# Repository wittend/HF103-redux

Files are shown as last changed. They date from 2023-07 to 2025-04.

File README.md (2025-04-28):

# NOTE: Just testing this REPO right now. - It may not work correctly!!
# HF103-redux
### A rework of an HF SDR using USB3 derived from a design developed by Oskar Stella, IK1XPV.
This variant is meant as a straw-man starting point for discussion of project options by members of the HamSCI and TAPR groups for scientific data-collection applications.  

It is a re-capture of design elements drawn from  Oskar's HF103, BBRF103, and other sources into a schematic drawn in KiCad.

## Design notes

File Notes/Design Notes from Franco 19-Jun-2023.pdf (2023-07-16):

# Design Notes from Franco 19-Jun-2023

Franco VENTURI\ Mon, 19 Jun, 21:51 (10 hours ago)
to me, tangerinesdr, Majid, Rob, Tom, John

## A few quick comments

### Maximum Throughput:

regarding the maximum throughput achievable with the FX3 the best place to start IMHO is Cypress AN86947 (https://www.infineon.com/dgdl/Infineon-AN86947_Optimizing_USB_3.0_Throughput_with_EZ-USB_FX3-ApplicationNotes-v05_00-EN.pdf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) - as you can see there the maximum (https://www.infineon.com/dgdl/Infineon-AN86947_Optimizing_USB_3.0_Throughput_with_EZ-USB_FX3-ApplicationNotes-v05_00-EN.pdf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) throughput is achieved using an AUTO DMA channel with the GPIF II interface, 32bit wide, and with a clock rate of 100MHz (and with 4 DMA buffer of 8kB each - bulk transfer mode)

### Important App Notes:

if I remember correctly, Oscar Steila IK1XPV design is based on the 'cyfxbulklpauto' example (you can find it in 'cyfx3sdk/firmware/dma_examples/cyfxbulklpauto' in the FX3 firmware SDK file 'fx3_firmware_linux.tar.gz'), and on a couple of very useful application notes from Cypress/Infineon: AN65974 "Designing with the EZ-USB FX3 slave FIFO interface" (https://www.infineon.com/dgdl/Infineon-AN65974_Designing_with_the_EZ-USB_FX3_Slave_FIFO_Interface-ApplicationNotes-v17_00-EN.pdf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), (https://www.infineon.com/dgdl/Infineon-AN65974_Designing_with_the_EZ-USB_FX3_Slave_FIFO_Interface-ApplicationNotes-v17_00-EN.pdf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)
and the 'ping-pong' DMA buffers approach shown in AN75779 "How to implement an image sensor interface using EZ-USB FX3 in a USB Video Class (UVC) framework" (https://www.infineon.com/dgdl/Infineon-AN75779How_to_Implement_an_Image_Sensor_Interface_with_EZ-USB_FX3_in_a_USB_Video_Class(UVC)_Framework-ApplicationNotes-v13_00-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 fileId=8ac78c8c7cdc391c017d073ad2b85f0d)) (https://www.infineon.com/dgdl/Infineon-AN75779_How_to_Implement_an_Image_Sensor_Interface_with_EZ-USB_FX3_in_a_USB_Video_Class_(UVC)_Framework-ApplicationNote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)

### Previous Code:

when I looked at what he did a few years ago I didn't think it was exceedingly difficult; I remember the one thing to get right is the design of the GPIF II state machine using the program 'GPIF II Designer' (that I think runs only on Windows), but we can definitely look at what Oscar did and follow his footsteps (I think the design of his GPIF II state machine is in his GitHub repository too, so we can use that as a starting point)

### Keep Things Simple:

if I have to give you one advice is to try to 'keep things as simple as possible'; this is what Oscar did in his design of the BBRF103, which he was able to design and make in a relatively short period of time. I think the important thing is to get a prototype out that works even if it is not perfect and meet all the specifications. We can always improve from that but at least the first step is done.

### Choice of ADC:

regarding the choice of the ADC I don't think 14bit or 16bit makes much of a difference in terms of ENOB, since I read somewhere about diminishing returns at those resolutions (can't find the link now); since the FX3 GPIF II works with 16/32 bits at a time, using a 14bit ADC would give us two extra bits for each sample: one could be used for the overflow bit, and the MSB for the PPS from the GPSDO, which I think is what Tom is doing in the TangerineSDR.

### General advice:

and finally I expect that someone will eventually come out with the "ClementineSDR+" that uses the LTC2208-16, since for some reason they are dirt cheap on AliExpress.

73,

Franco K4VZ

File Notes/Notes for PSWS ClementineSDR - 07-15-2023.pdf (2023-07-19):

# Notes for PSWS ClementineSDR - 07-15-2023

## Includes progress with HF103-redux

Dave Witten, KD0EAG

## Recent activity

Continued work on redraw/capture of the design elements of Oskar Stella's HF103 and BBRF103 radio designs in KiCad. The HF103 is an HF only version. The BBRF103 design supports VHF/UHF and is a more direct predecessor of the RF-666, RF-888, and RF-888 MK-II designs. All may be descendants of a project called booyaSDR. All use the Cypress CYFX3SDK or its component chips. Several different LTC ADC chips are used, All very similar.
Introduced myself to Oskar Stella by email. Received his kind permission to ask questions (sparingly) about his designs.
Created an initial private GitHub repo for the resulting KiCad project. Invited some initial interested parties as collaborators. It is early-daze for this, lots to learn about how to make a KiCad project hang together in GitHub.
Though this schematic and all related documents will be open to all, I'm holding them 'private' until I'm sure that the repo works as intended.
Received a booyaSDR kit for study. So have Dave Larsen and Mike Hauan. Seller indicates that he has run out of stock due to Cypress CYFX3SDK's being unavailable. This is true for US distributors, but the SDK's are available (often at a premium) from overseas suppliers.
The individual SDK components seem to be in good supply.
Received an LTC2208-16 board to supplement the LTC2208-14 board that I have. Unfortunately, the one that I have is a variant that supports input data at >140 MHz. I should have bought the version that supports 1 MHz > 70 MHz. Not sure that I want to buy another board for ~$ 250.00.

## Plans for the next week:

Work on requirements document (!!)
Try to get to work with the Cypress SDK examples (!)
Make sure everyone who needs access to the GitHub has it.
Make especially sure that people who are interested are communicating about clocking issues are keeping everyone informed of their strategies.
Try to solicit feedback concerning schematic design.

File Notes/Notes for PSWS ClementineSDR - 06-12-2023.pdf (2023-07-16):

# Notes for PSWS ClementineSDR - 06-12-2023

Paths to pursue:

1. Platform revision
Platform Requirements
As much of functionality described in "TangerineSDR - Architecture and System Requirements" (Tom McDermott rev. 0.3, 30 May 2019) as possible.
2. Radio subsystem only
Implement as much of the functionality described in "TangerineSDR RF Receiver Module (RXM-5001D)" (Document Number: TSDR-RXM-5001D-REQ, Tom McDermott rev. 0.4, November 22, 2019) as possible.
Use existing RX-888 devices for RF Data Collection.
How to integrate?
Create adapter based on the Cypress FX3 SuperSpeed USB 3.0 peripheral controller to interface the existing TangerineSDR receiver module.
How much bandwidth support?
Coherent receiver support?
Design customized receiver based on the RX-888/BBRF103 design. Which A/D chip?
ADC9648 [dual-channel 14-Bit, 125 MSPS/105 MSPS, 1.8 V Dual] LTC2208-14/16 [14-Bit, 130Msps ADC].
???
Use For front end?
LTC6420-20 [dual-channel differential ADC driver with a fixed gain of 20 dB gain].
2. One Receiver or Two?
3. Features added:
Front end conditioning,
GPSDO discipline,
Time-stamping, etc.
4. Features removed:
RT820T2 VHF tuning?
3. Software integration
Verify that software drivers for intended platforms support existing use cases.
Understand organization and configuration of KA9Q-radio components relevant to project. Integration of data capture and collection into the HamSCI/PSWS storage architecture.
4. Immediate Actions:

Make certain that all existing HamSCi PSWS documentation is archived and accessible for future reference.
Investigate configuration of KA9Q-radio and understand its configuration.
Collect/Write documentation of KA9Q-radio and define its use as relates to this project. Acquire and test RX-888 devices to characterize their strengths/weaknesses to meet current needs.
Document fittness to purpose of existing RX-888 devices.
Acquire development tools required for customized design based on RX-888/BBRF103 designs.
Create sharable working schematic using KiCad.
Create sharable schematic and board designs for interface to existing TangerineSDR RF Receiver Module (RXM-5001D).
Create Github Repo for all documents and designs.
5. Development Tools:
CYUSB3Kit-003 (USB3 Interface dev. board) [Newark.uk, AliExpress]. CYUSB3Kit-007 (CPLD accessory board) [Newark.uk, AliExpress]. EZ-USB FX3 Software Development Kit [Infineon].
SuperSpeed Device Design by Example (book) [Amazon https://www.amazon.com/dp/1500588059?psc=1].
USB Complete v5 (book) [Amazon https://www.amazon.com/USB-Complete-Developers-Guide-Guides/dp/1931448280/134-6836790-4507607?psc=1].
AD/LTC Development board for ADC to be used. [Mouser, best bet].
KiCad footprints, symbols, 3D models for chips to be used [Ultra Librarian, various sources].

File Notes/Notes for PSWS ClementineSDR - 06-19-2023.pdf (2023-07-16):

# Notes for PSWS ClementineSDR - 06-19-2023

My (Dave, KD0EAG) activities during past week:

1. Track/receive Developer kits for CYUSB3kit
In hand (for sure) 1 CYSUB3Kit-003 board.
Hope to have two more CYSUB3Kit-003 boards by tonight (1 for Majid).
In hand (for sure) CYUSB3kit-007 CPLD add on board.
Hope to receive at least 1 more CYUSB3kit-007 CPLD add on board by end of month.
2. Productive call with Franco .
Discussed project goals and background.
Discussed path to hardware design.
Agreed that KiCad (free, open source) reference schematic is a good initial goal. Plan to have additional meets with interested participants as needed.
Agreed that design might hold some components external to facilitate future flexibility of design.
Front-end conditioning (filtering).
some aspects of time discipline.
some aspects of time stamping.
3. Attempted to keep interested parties informed of activities and interesting found documents. (Let me know if I am not including you properly).
4. Reading "SuperSpeed Device Design by Example" by John Hyde [Amazon https://www.amazon.com/dp/1500588059?psc=1].
Getting started with examples in this book.
5. Working on "Requirements" spreadsheet derived from:
"TangerineSDR RF Receiver Module (RXM-5001D) Requirements Document"
Document Number: TSDR-RXM-5001D-REQ, version 0.4 Date: Nov. 22, 2019
provided by Tom McDermott

My action Items:

1. Attempt to build a demo project for the FX3. Maybe more than one. Start with CPLD FX3-Slave FIFO CPLD Demo.
Will CPLD functionality be needed in final design (for timing stuff?)
Will I2C be needed for control functions?
2. Read BBRF103 and RX-888 code closely to better understand which sort of applications are possible and best suited to SDR designs.

from reading, it appears that an asynchronous FX3 Slave FIFO design may be the fastest and most appropriate architecture.
This may be a difficult strategy to design well. Don't know.
Need to find out what has been done in the past.
3. Choose ADC chips for reference schematic(s).
Probably choose LTC2208CUP-14 for first efforts because it is small and I have the DEMO854D-D board in hand.
Also have the AD9648-125EBZ board in hand, but it is bigger and looks complicated.
4. Need to discuss these things with Interested parties, esp. Tom McDermott, John Ackerman (maybe Franco, Rob, Phil when they return).
5. Get dev. tools packaged and sent to Majid ASAP (hopefully today if they arrive).
6. What else??

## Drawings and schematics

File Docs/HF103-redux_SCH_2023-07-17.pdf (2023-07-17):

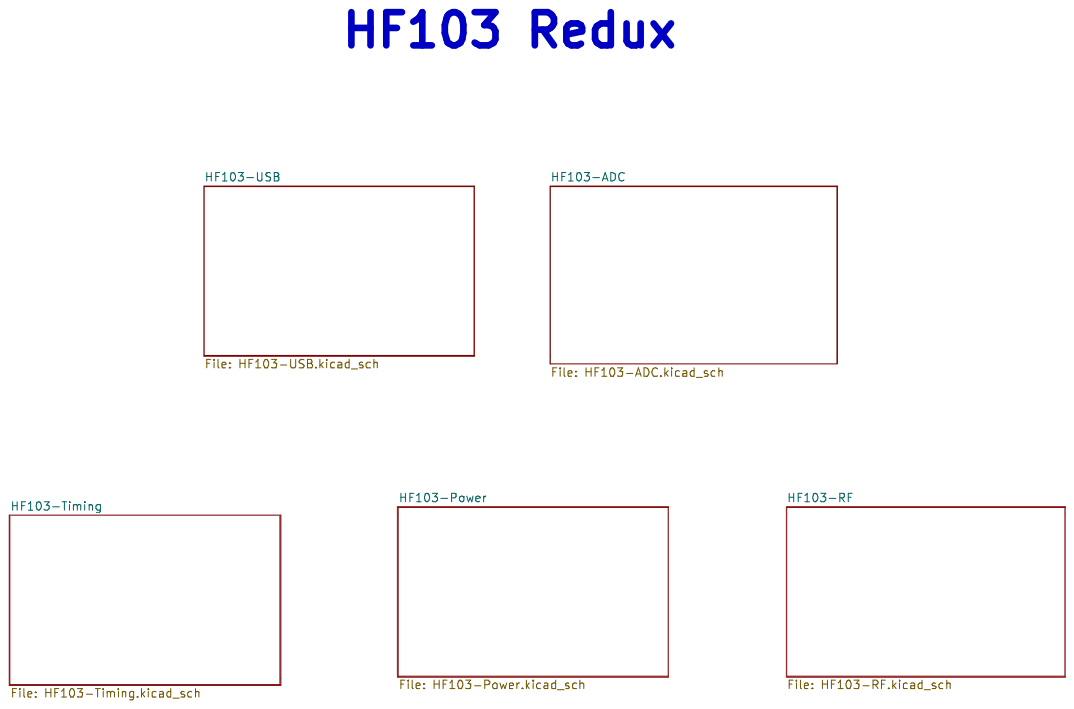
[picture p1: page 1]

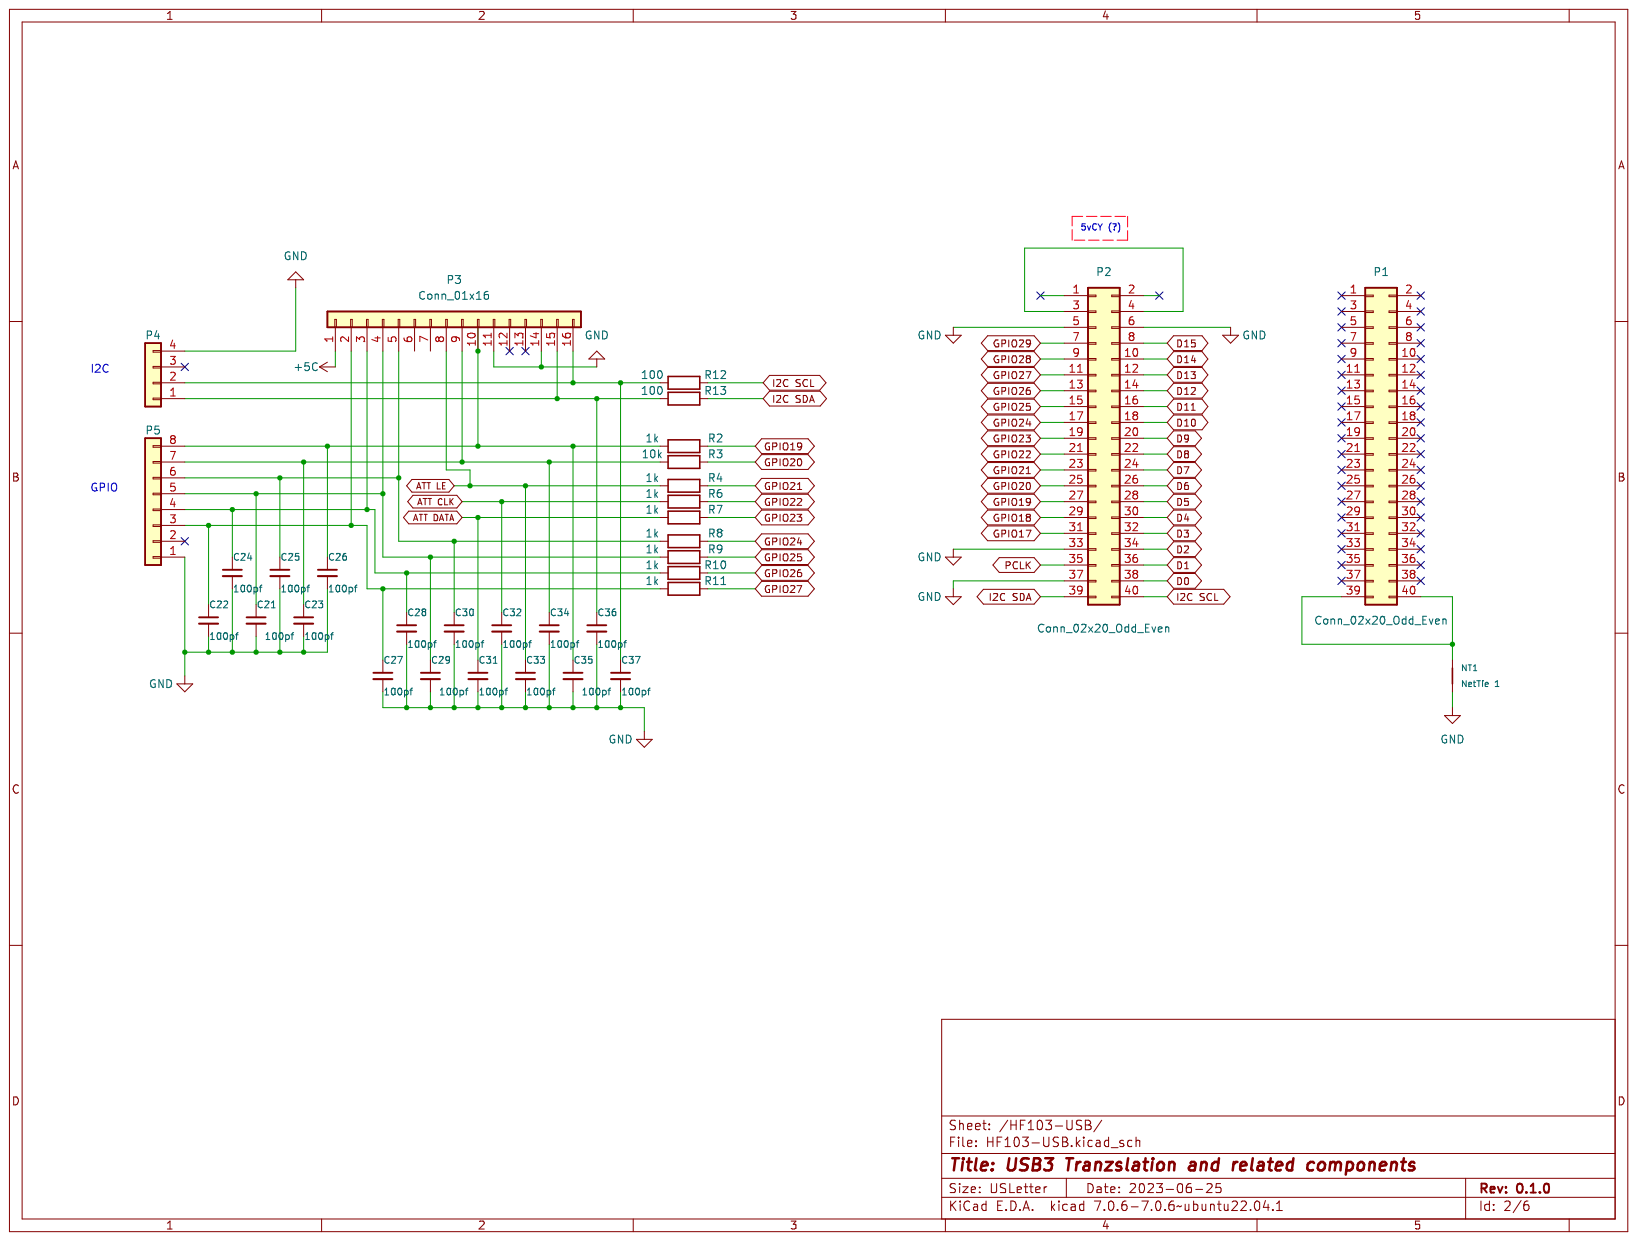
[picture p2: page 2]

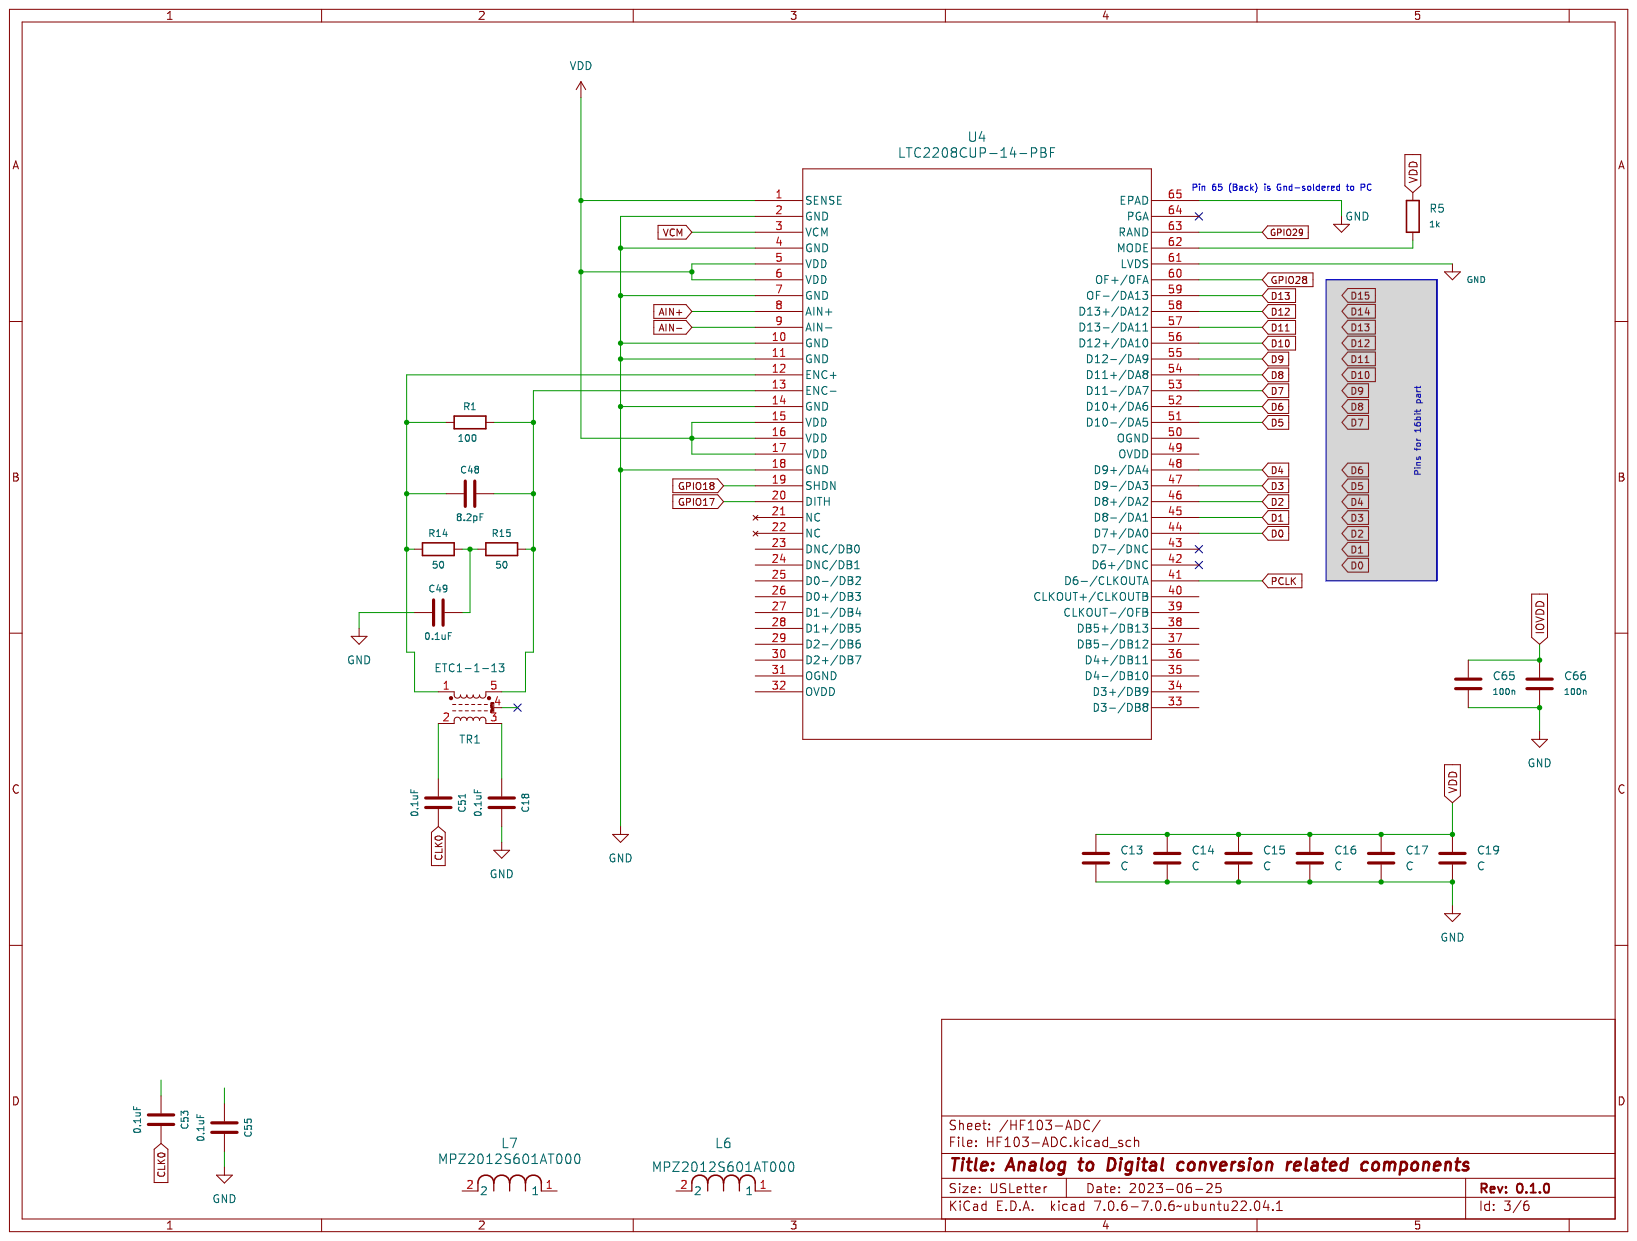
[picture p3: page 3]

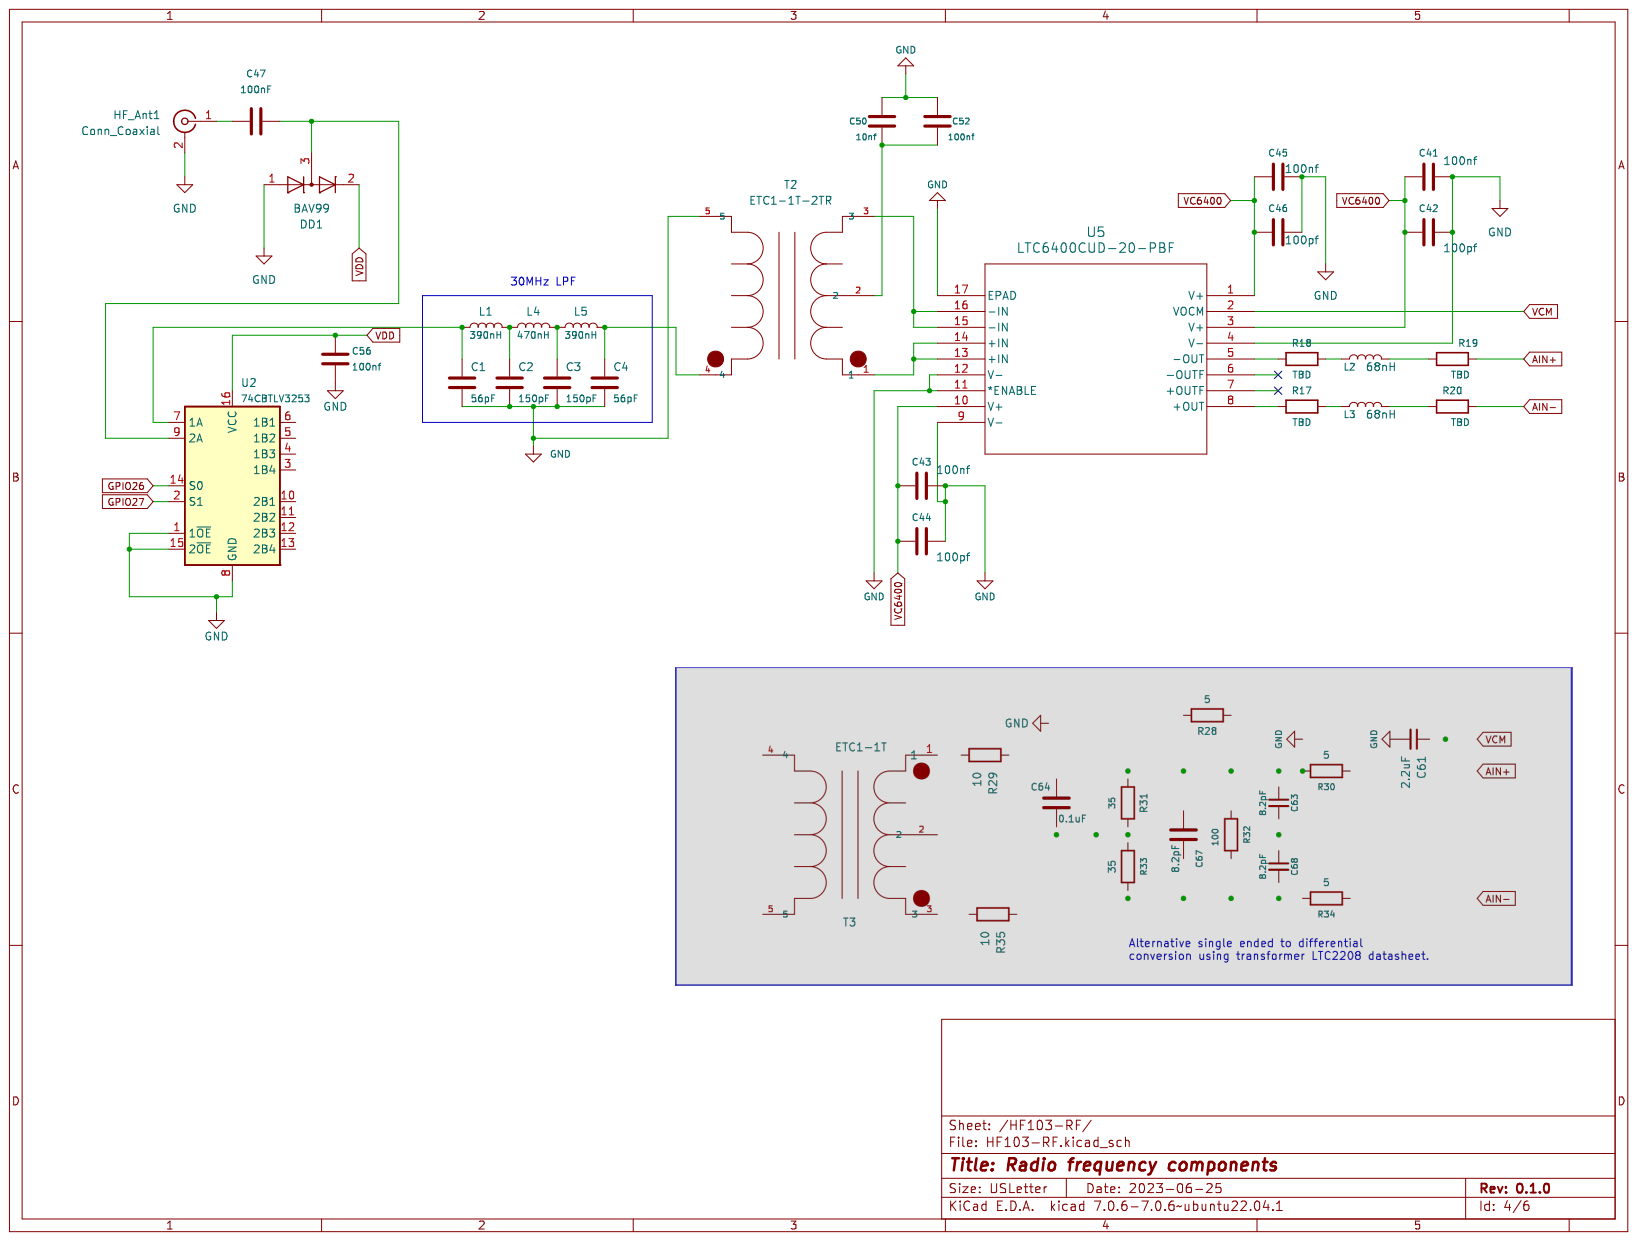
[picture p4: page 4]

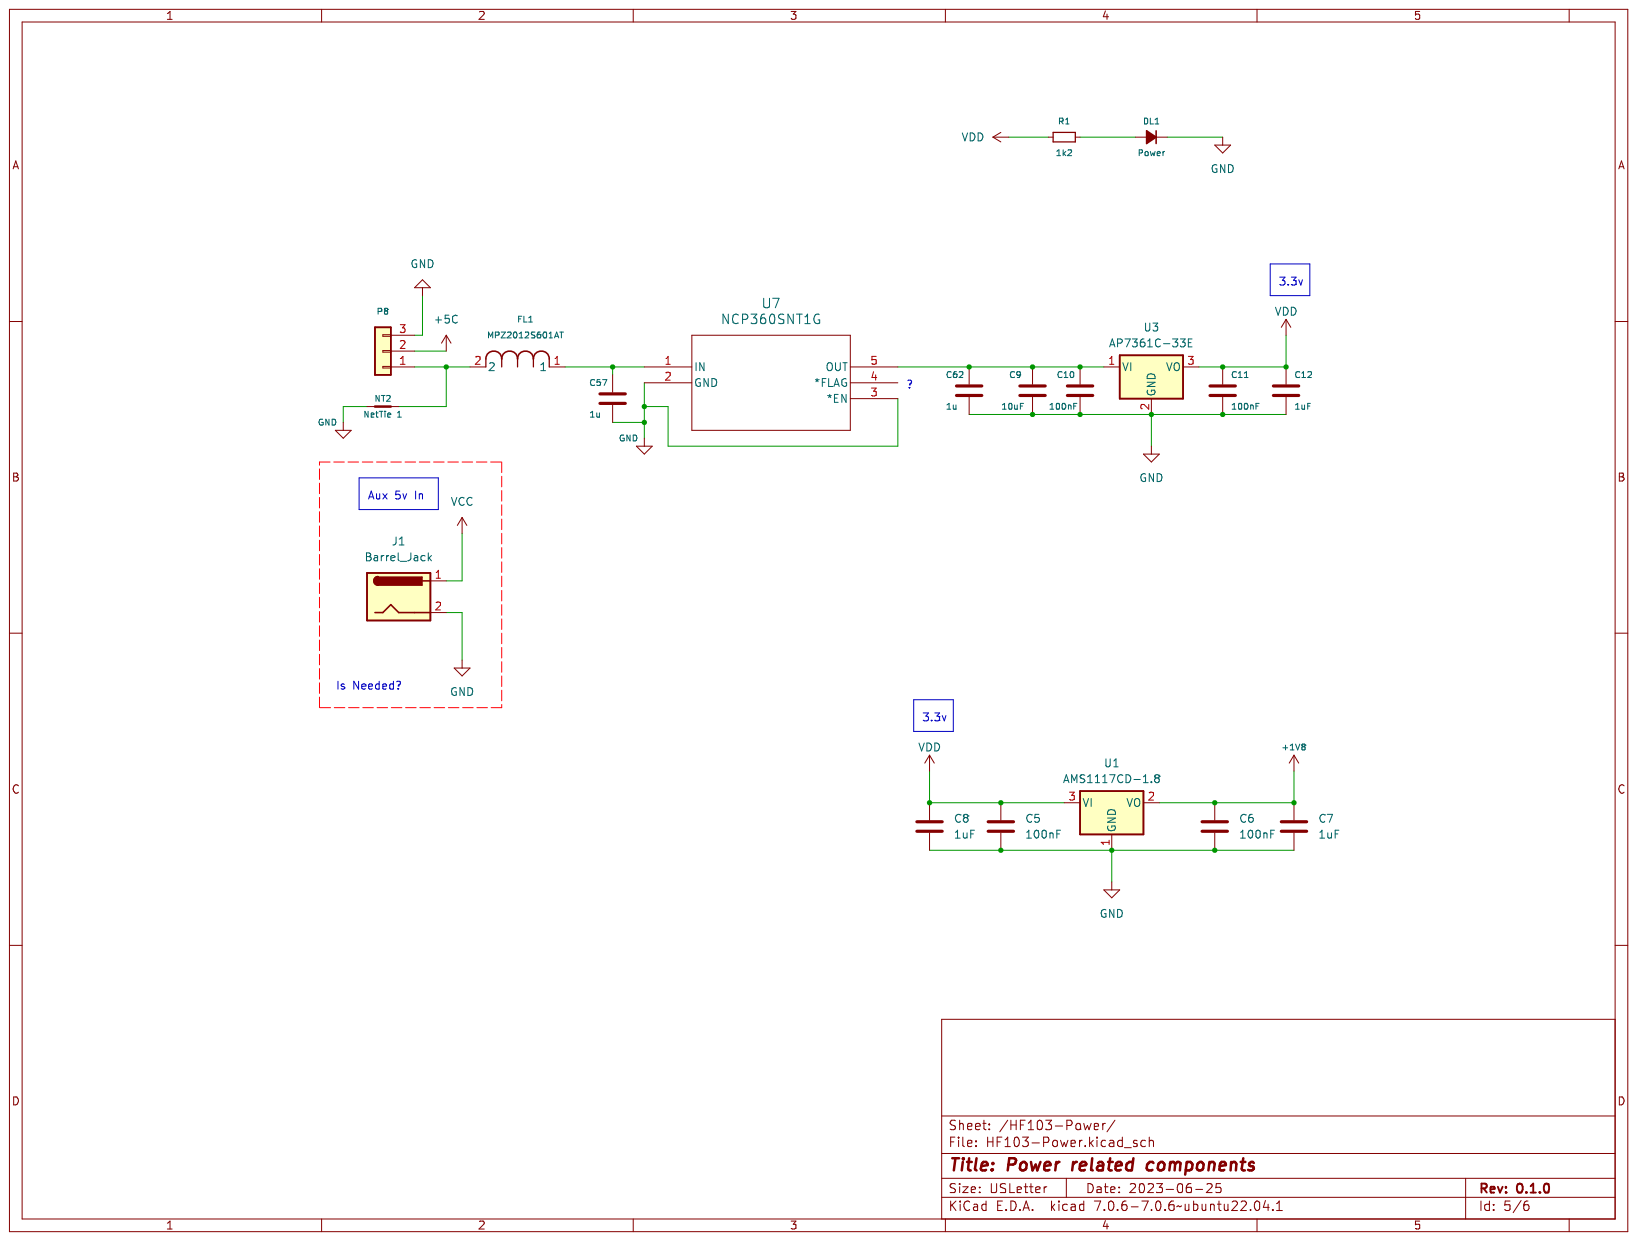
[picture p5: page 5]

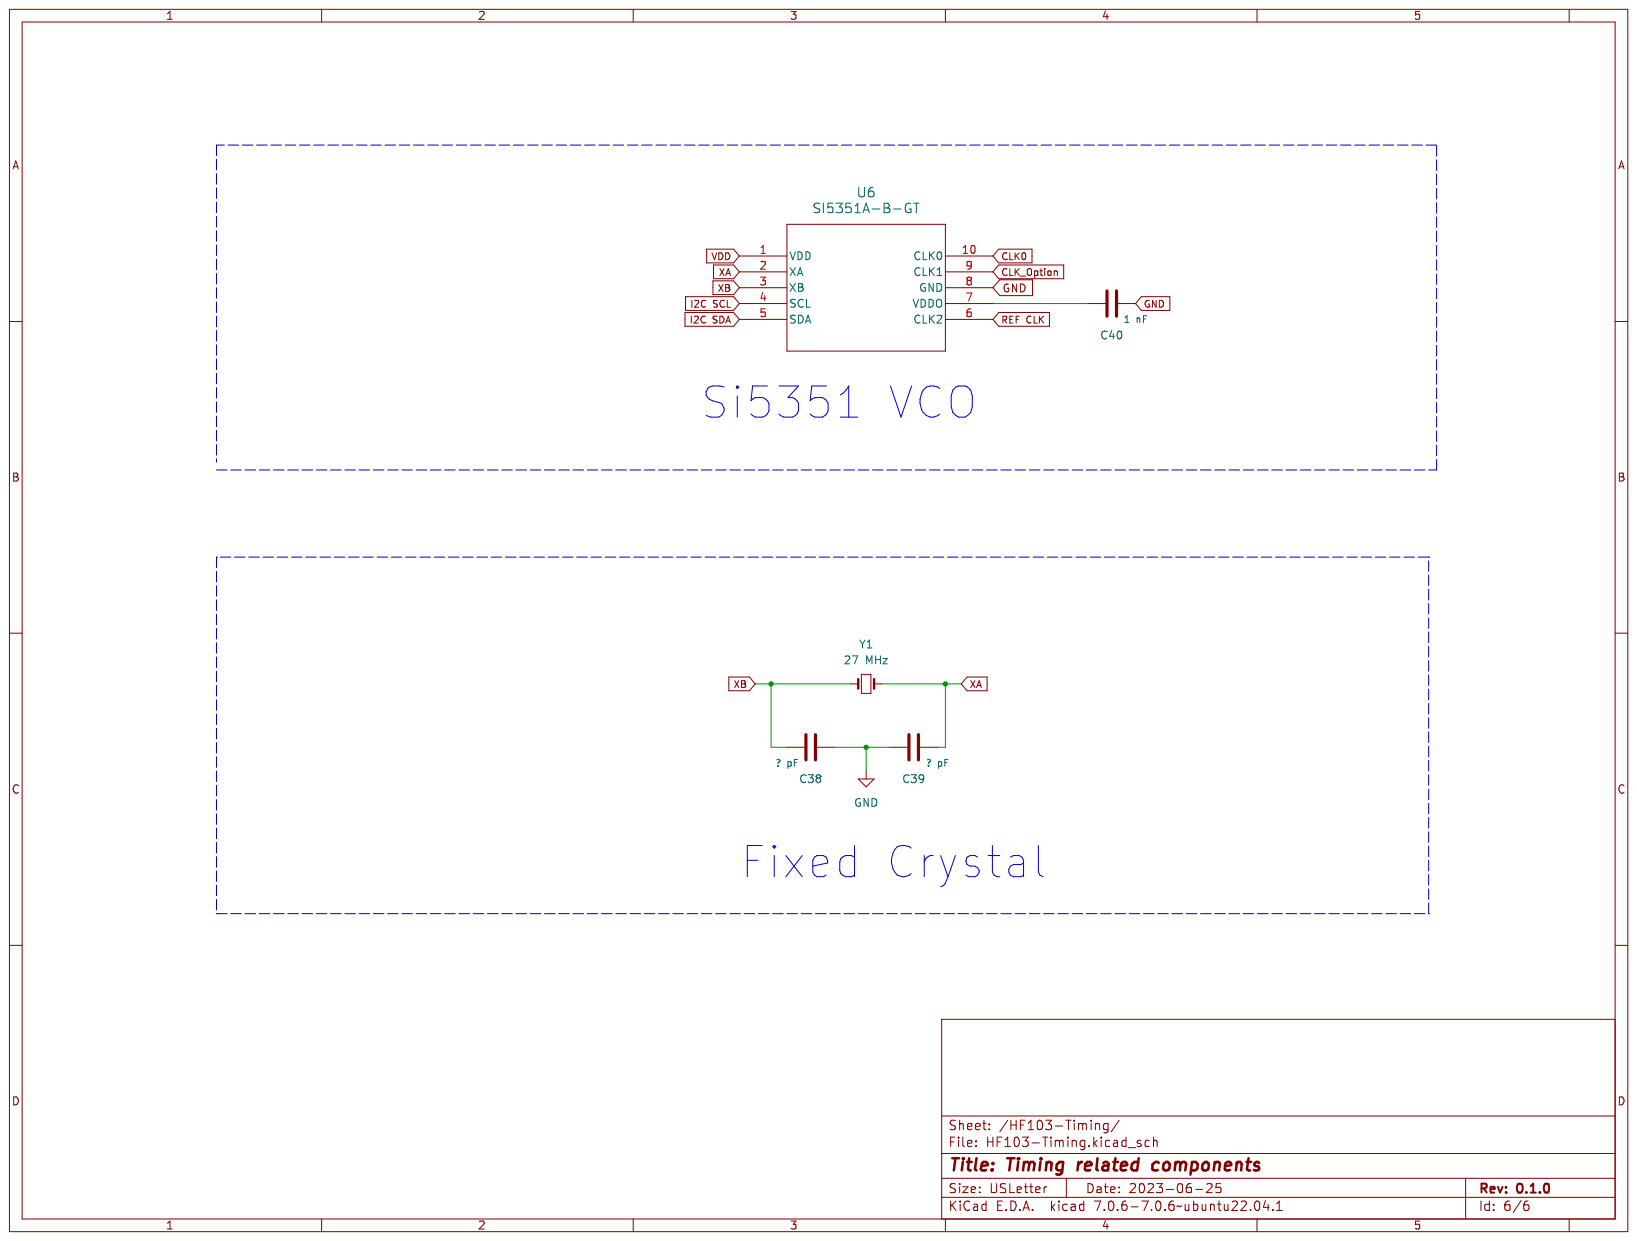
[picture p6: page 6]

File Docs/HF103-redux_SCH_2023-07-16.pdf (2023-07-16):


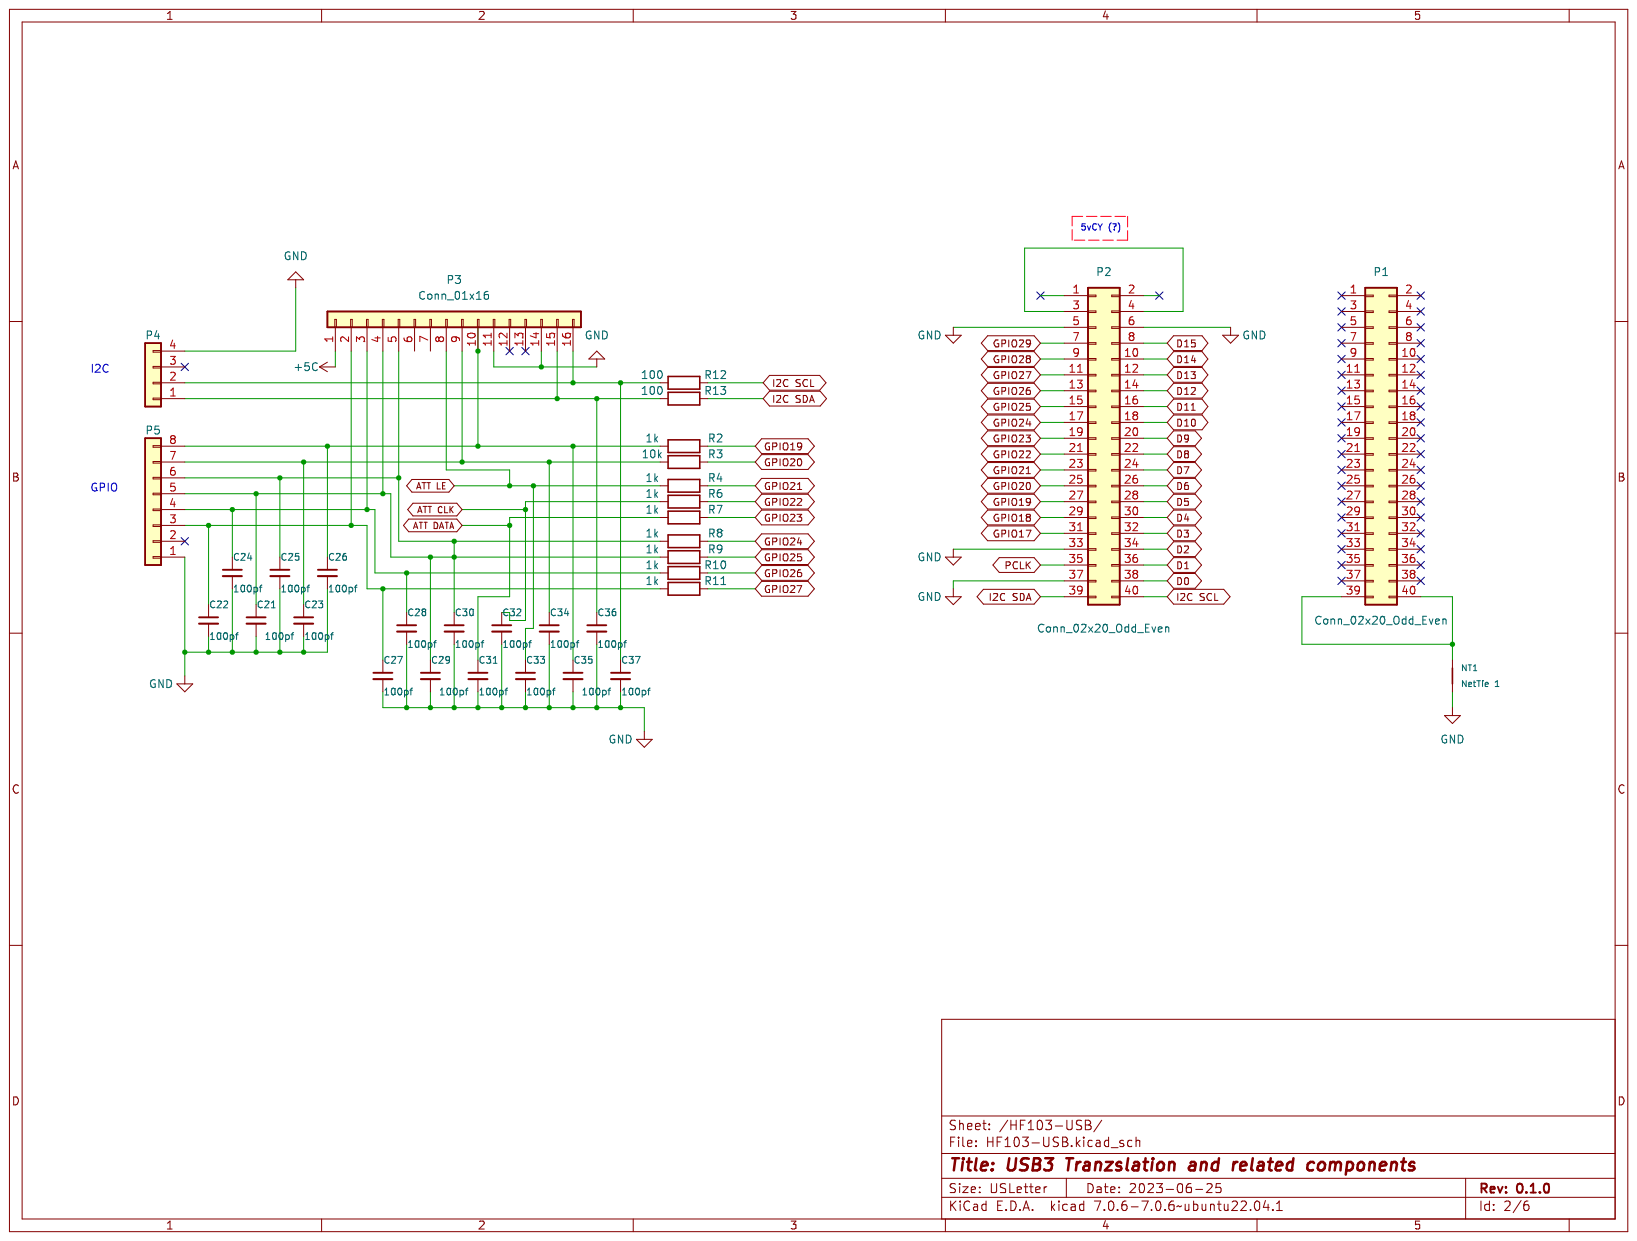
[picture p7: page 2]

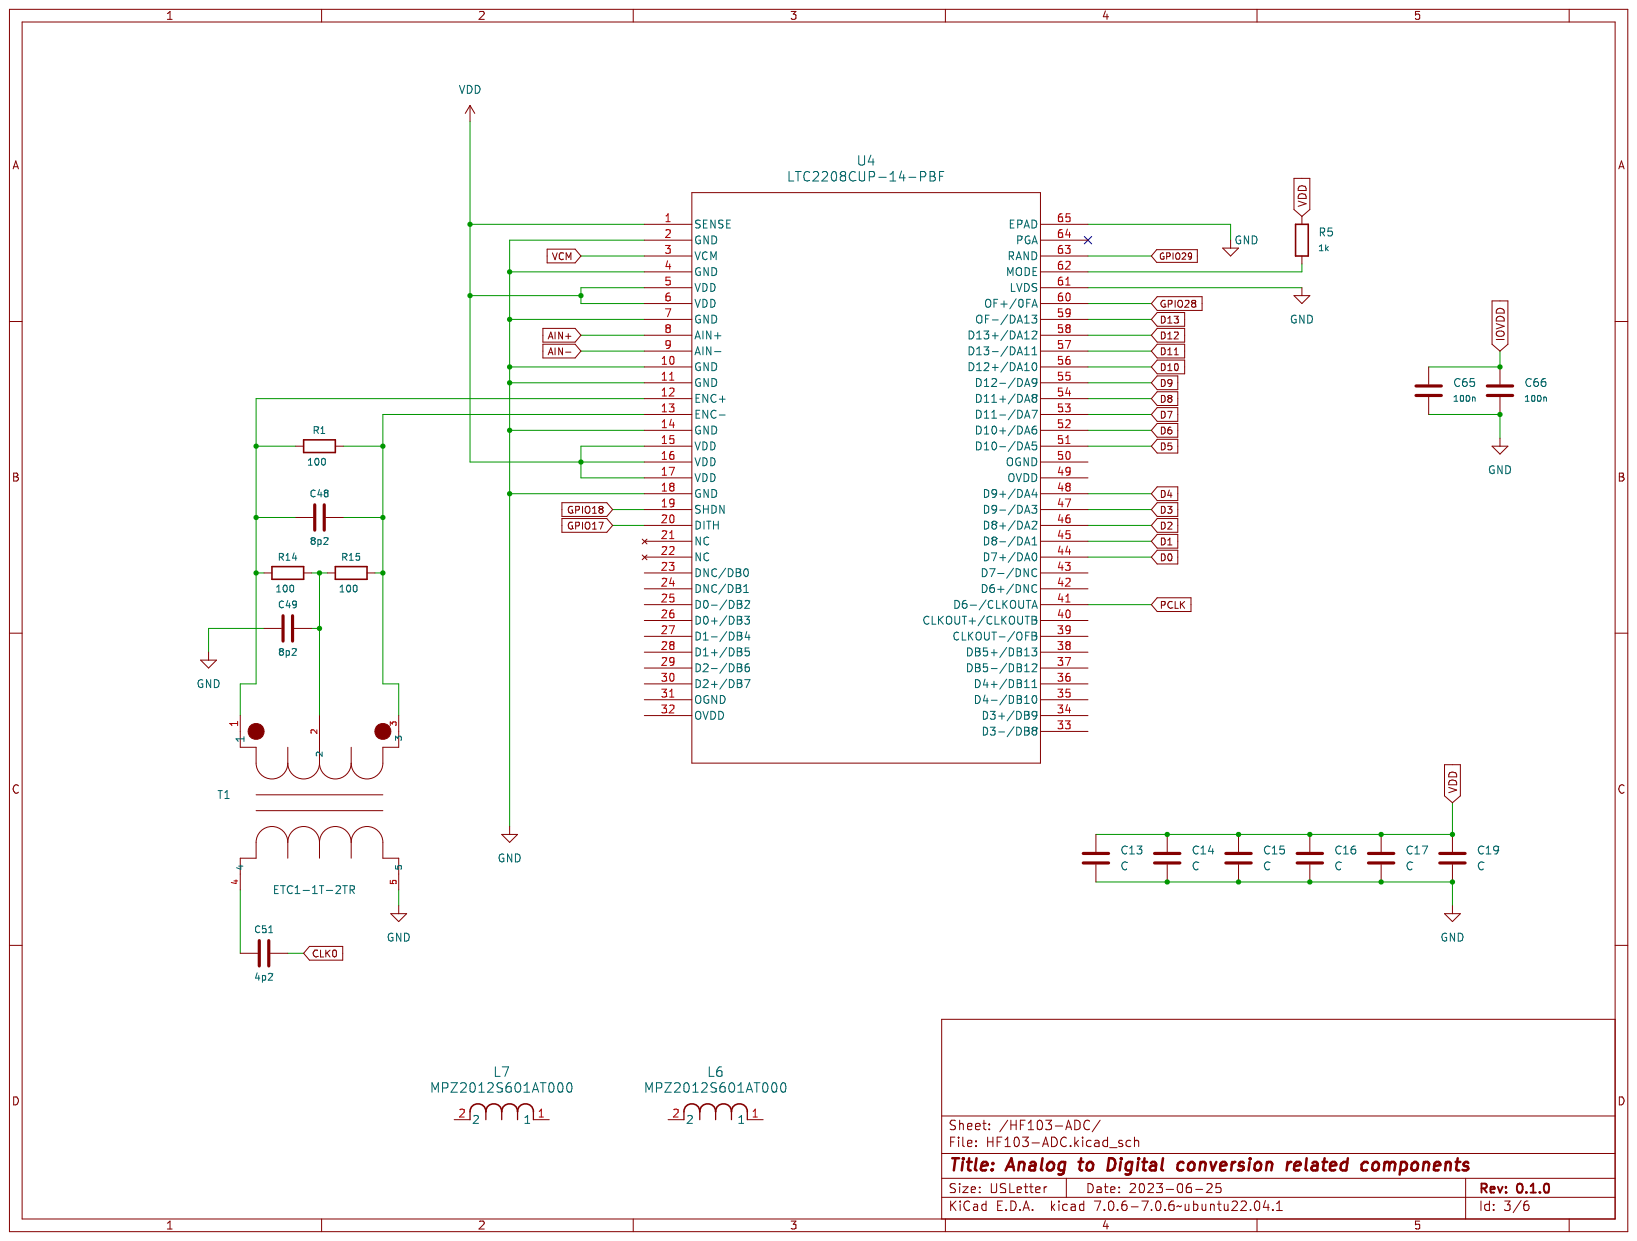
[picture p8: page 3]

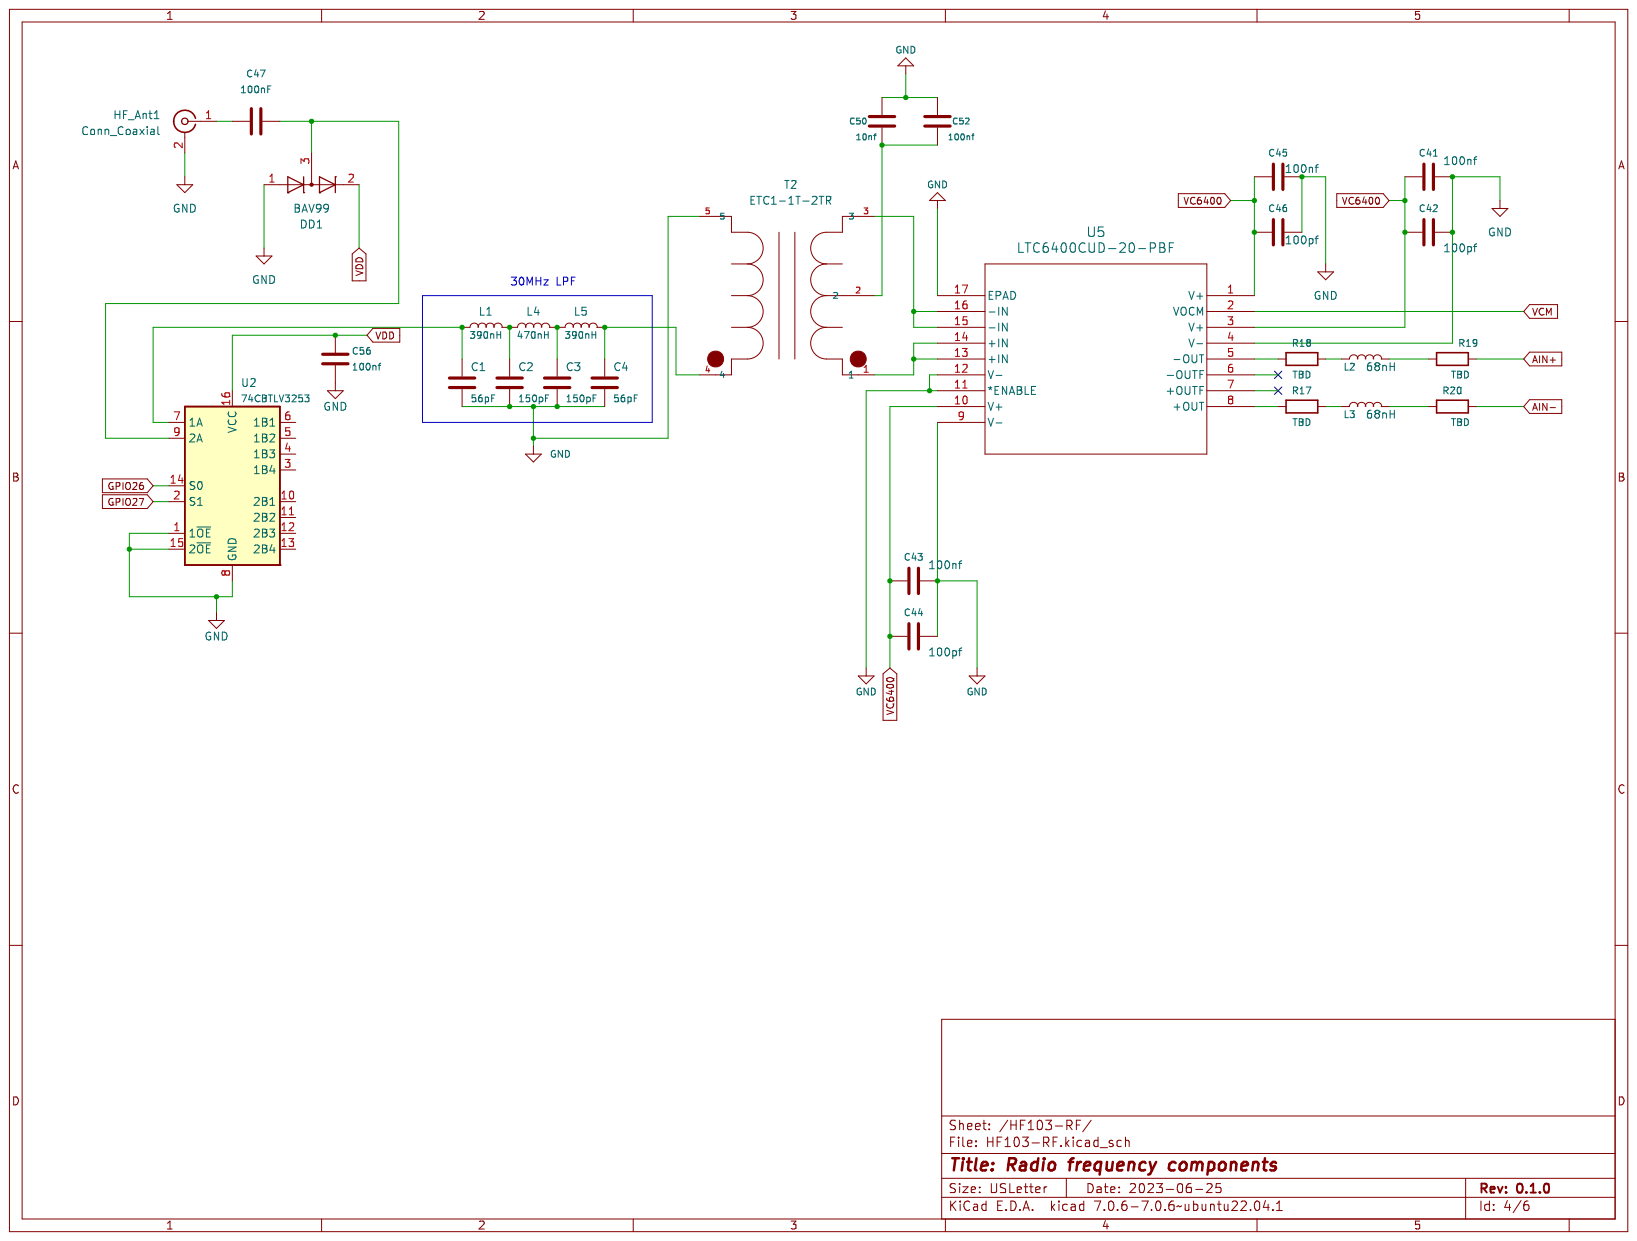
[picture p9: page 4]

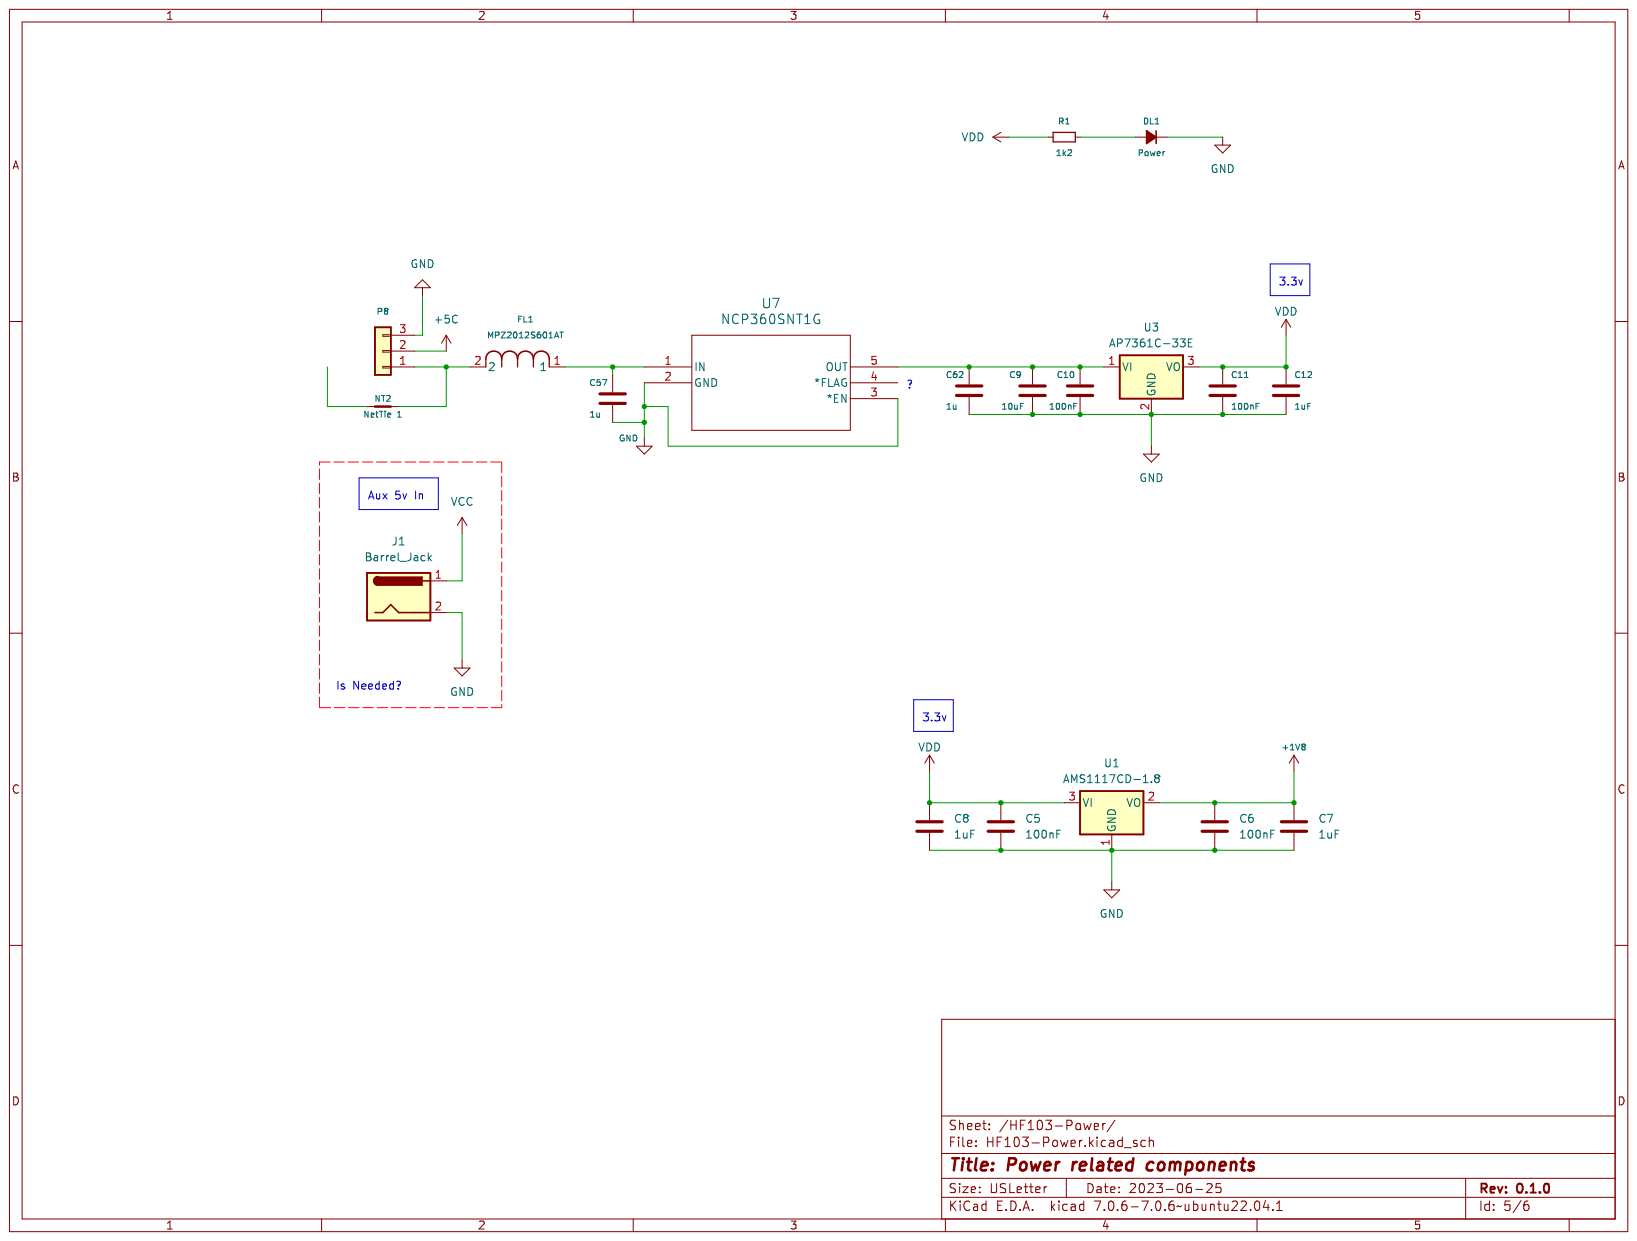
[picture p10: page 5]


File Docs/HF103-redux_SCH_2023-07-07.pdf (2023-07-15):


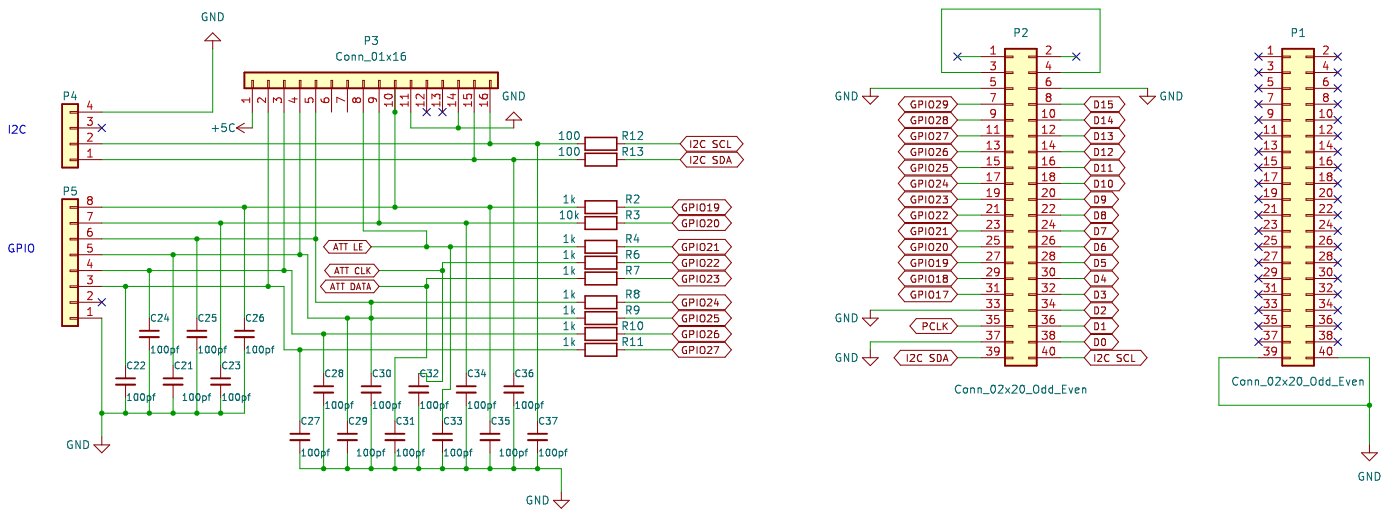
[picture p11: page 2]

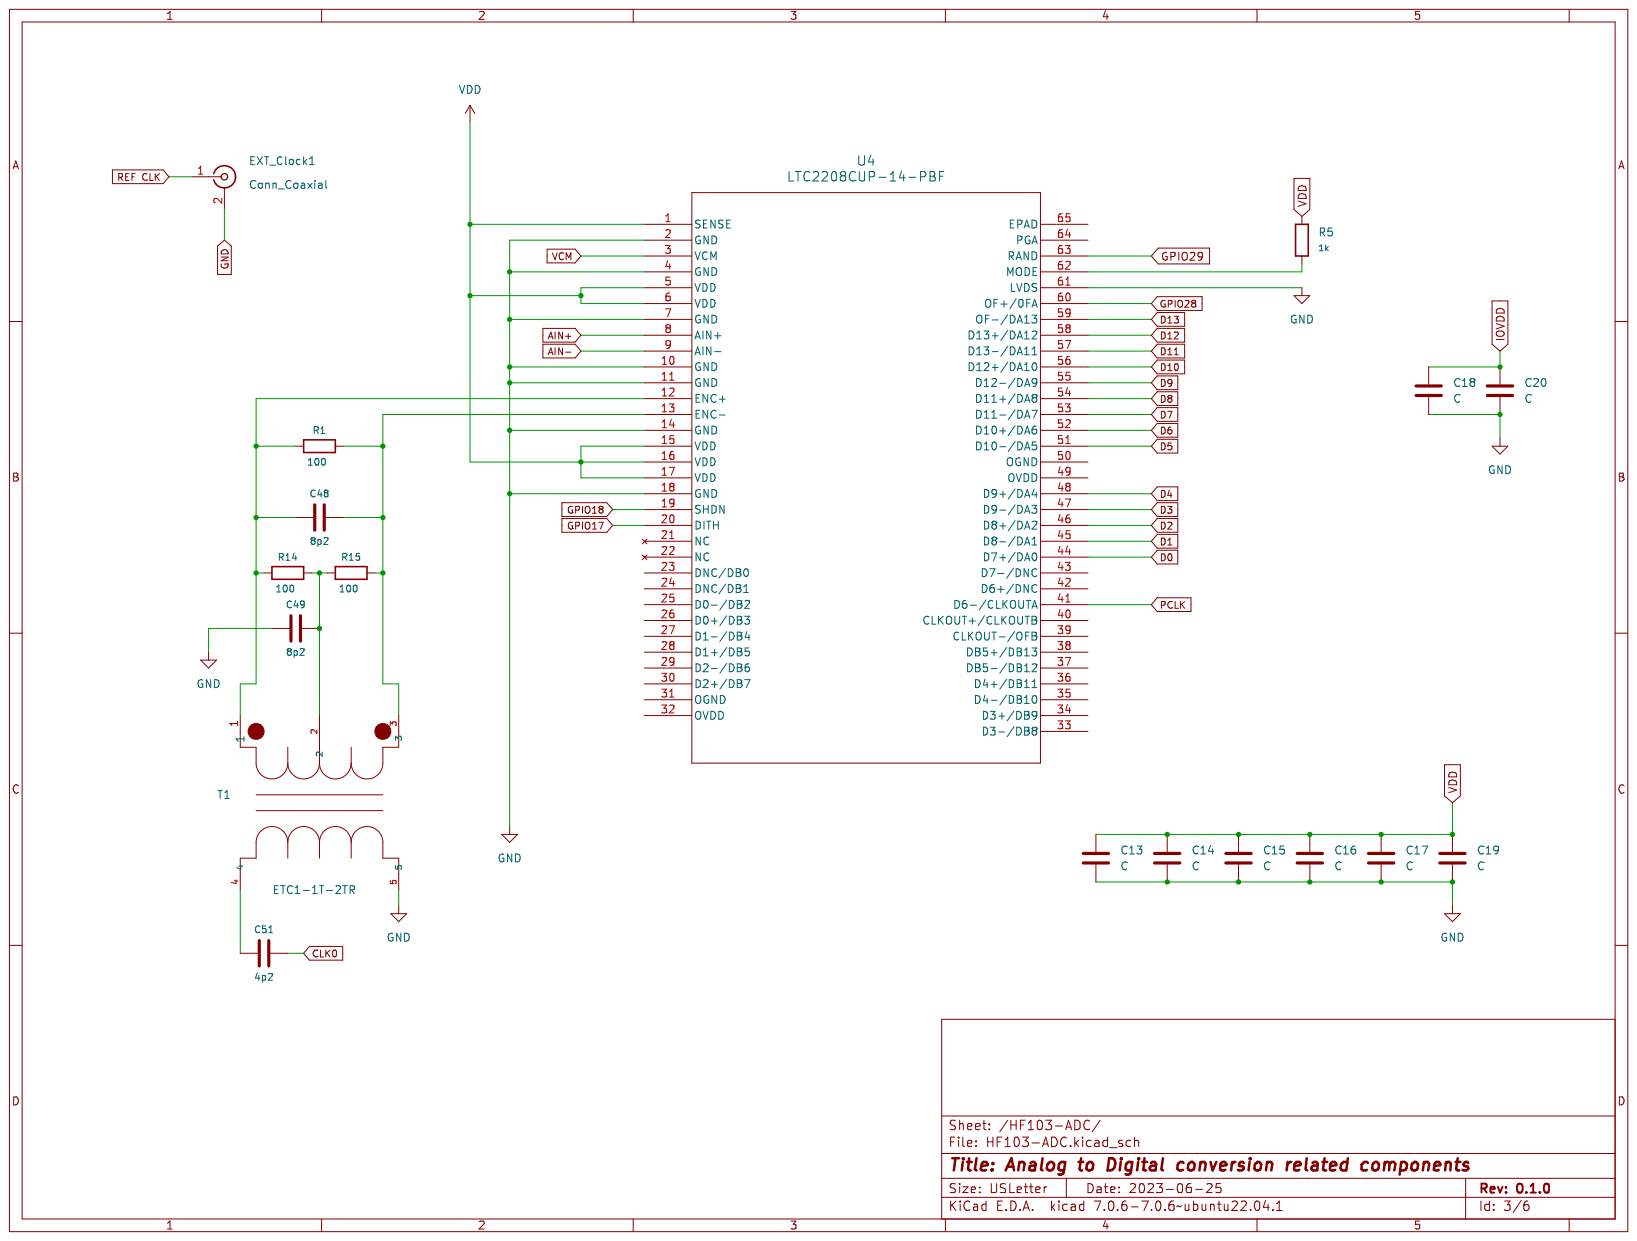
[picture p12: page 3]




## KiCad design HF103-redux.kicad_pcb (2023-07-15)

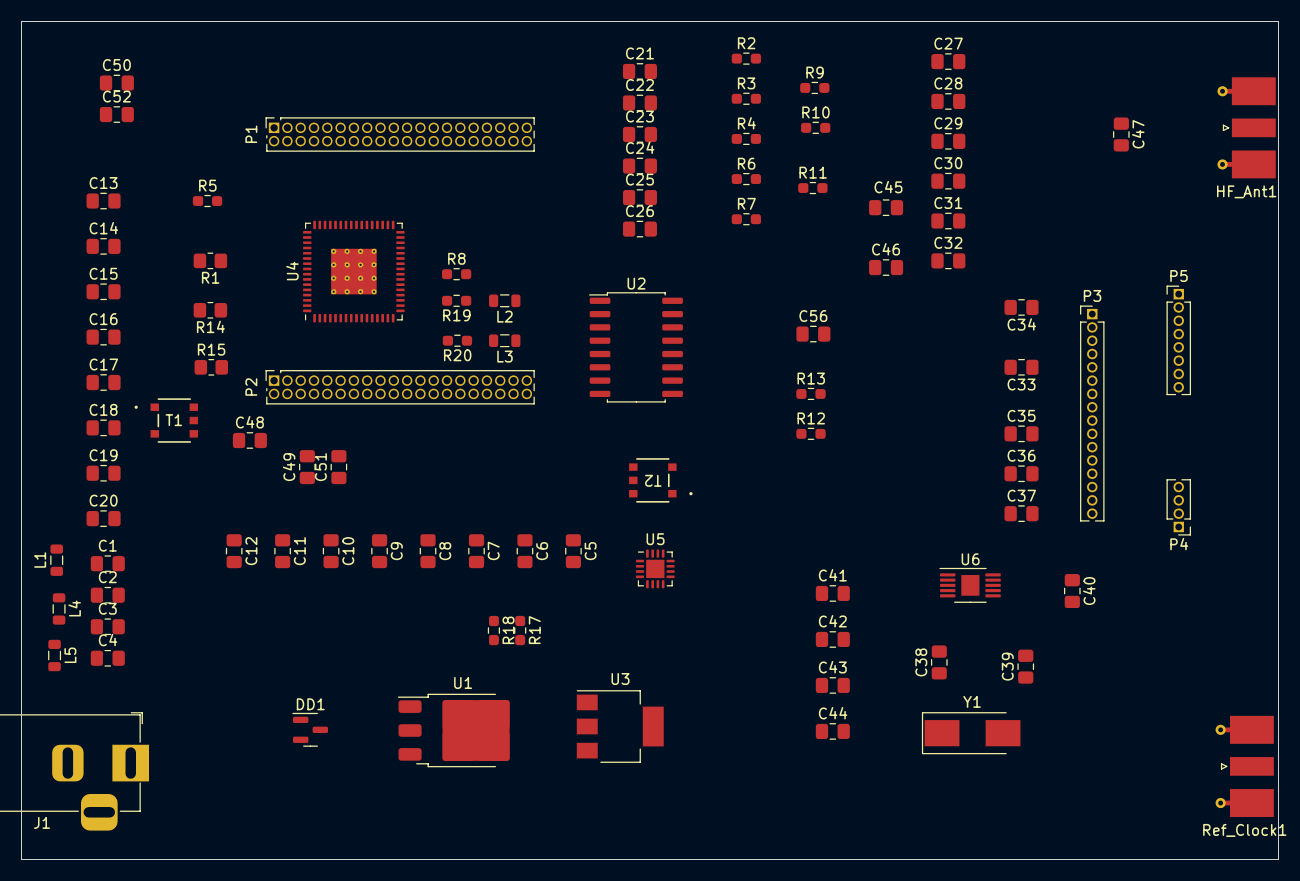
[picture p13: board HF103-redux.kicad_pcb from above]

Board: 2 copper layers, 120.0 x 80.0 mm, 95 parts (0 on the bottom side), 75 nets, no tracks yet.

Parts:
C1, C4: 56pF; C_0805_2012Metric_Pad1.18x1.45mm_HandSolder
C2, C3: 150pF; C_0805_2012Metric_Pad1.18x1.45mm_HandSolder
C5, C6, C10, C11, C47: 100nF; C_0805_2012Metric_Pad1.18x1.45mm_HandSolder
C7, C8, C12: 1uF; C_0805_2012Metric_Pad1.18x1.45mm_HandSolder
C9: 10uF; C_0805_2012Metric_Pad1.18x1.45mm_HandSolder
C13, C14, C15, C16, C17, C18, C19, C20: C; C_0805_2012Metric_Pad1.18x1.45mm_HandSolder
C21, C22, C23, C24, C25, C26, C27, C28, C29, C30, C31, C32, C33, C34, C35, C36, C37, C42, C44, C46: 100pf; C_0805_2012Metric_Pad1.18x1.45mm_HandSolder
C38, C39: ? pF; C_0805_2012Metric_Pad1.18x1.45mm_HandSolder
C40: 1 nF; C_0805_2012Metric_Pad1.18x1.45mm_HandSolder
C41, C43, C45, C52, C56: 100nf; C_0805_2012Metric_Pad1.18x1.45mm_HandSolder
C48, C49: 8p2; C_0805_2012Metric_Pad1.18x1.45mm_HandSolder
C50: 10nf; C_0805_2012Metric_Pad1.18x1.45mm_HandSolder
C51: 4p2; C_0805_2012Metric_Pad1.18x1.45mm_HandSolder
DD1: BAV99; SOT-23
HF_Ant1: Conn_Coaxial; SMA_Molex_73251-2120_EdgeMount_Horizontal
J1: Barrel_Jack; BarrelJack_Horizontal
L1, L5: 390nH; L_0805_2012Metric
L2, L3: 68nH; L_0805_2012Metric
L4: 470nH; L_0805_2012Metric
P1, P2: Conn_02x20_Odd_Even; PinSocket_2x20_P1.27mm_Vertical
P3: Conn_01x16; PinHeader_1x16_P1.27mm_Vertical
P4: Conn_01x04; PinHeader_1x04_P1.27mm_Vertical
P5: Conn_01x08; PinHeader_1x08_P1.27mm_Vertical
R1, R14, R15: 100; R_0805_2012Metric_Pad1.20x1.40mm_HandSolder
R2, R4, R5, R6, R7, R8, R9, R10, R11: 1k; R_0603_1608Metric_Pad0.98x0.95mm_HandSolder
R3: 10k; R_0603_1608Metric_Pad0.98x0.95mm_HandSolder
R12, R13: 100; R_0603_1608Metric_Pad0.98x0.95mm_HandSolder
R17, R18, R19, R20: TBD; R_0603_1608Metric_Pad0.98x0.95mm_HandSolder
Ref_Clock1: Conn_Coaxial; SMA_Molex_73251-2120_EdgeMount_Horizontal
T1, T2: ETC1-1T-2TR; ETC1-1-13TR_MCM
U1: AMS1117CD-1.8; TO-252-3_TabPin2
U2: 74CBTLV3253; SO-16_5.3x10.2mm_P1.27mm
U3: AP7361C-33E; SOT-223-3_TabPin2
U4: LTC2208CUP-14-PBF; QFN-64-1EP_9x9mm_P0.5mm_EP4.35x4.35mm_ThermalVias
U5: LTC6400CUD-20-PBF; QFN-16-1EP_3x3mm_P0.5mm_EP1.75x1.75mm
U6: SI5351A-B-GT; MSOP-10-1EP_3x3mm_P0.5mm_EP1.73x1.98mm
Y1: 27 MHz; Crystal_SMD_0603-2Pin_6.0x3.5mm_HandSoldering

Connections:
+1V8: C6.1, C7.1, U1.2 (VO)
AIN+: R19.1, U4.8 (AIN+)
AIN-: R20.1, U4.9 (AIN-)
ATT CLK: C32.1, R6.2
ATT DATA: C31.1, R7.2
ATT LE: C33.1, P3.8, R4.2
CLK0: C51.2, U6.10 (CLK0)
D0: P2.38, U4.44 (D7+/DA0)
D1: P2.36, U4.45 (D8-/DA1)
D2: P2.34, U4.46 (D8+/DA2)
D3: P2.32, U4.47 (D9-/DA3)
D4: P2.30, U4.48 (D9+/DA4)
D5: P2.28, U4.51 (D10-/DA5)
D6: P2.26, U4.52 (D10+/DA6)
D7: P2.24, U4.53 (D11-/DA7)
D8: P2.22, U4.54 (D11+/DA8)
D9: P2.20, U4.55 (D12-/DA9)
D10: P2.18, U4.56 (D12+/DA10)
D11: P2.16, U4.57 (D13-/DA11)
D12: P2.14, U4.58 (D13+/DA12)
D13: P2.12, U4.59 (OF-/DA13)
GND: C1.2, C2.2, C3.2, C4.2, C5.2, C6.2, C7.2, C8.2, C9.2, C10.2, C11.2, C12.2, C13.2, C14.2, C15.2, C16.2, C17.2, C18.2, C19.2, C20.2, C21.2, C22.2, C23.2, C24.2, C25.2, C26.2, C27.2, C28.2, C29.2, C30.2, C31.2, C32.2, C33.2, C34.2, C35.2, C36.2, C37.2, C38.1, C39.2, C40.1, C41.1, C42.1, C43.1, C44.1, C45.1, C46.1, C49.1, C50.1, C52.1, C56.2, DD1.1 (K), HF_Ant1.2 (Ext), J1.2, P1.39, P1.40, P2.5, P2.6, P2.33, P2.37, P3.11, P3.14, P4.4, P5.1, Ref_Clock1.2 (Ext), T1.5, T2.5, U1.1 (GND), U2.1 (1~OE), U2.8 (GND), U2.15 (2~OE), U3.2 (GND), U4.2 (GND), U4.4 (GND), U4.7 (GND), U4.10 (GND), U4.11 (GND), U4.14 (GND), U4.18 (GND), U4.61 (LVDS), U5.4 (V-), U5.9 (V-), U5.11 (*ENABLE), U5.12 (V-), U5.17 (EPAD), U6.8 (GND)
GPIO17: P2.31, U4.20 (DITH)
GPIO18: P2.29, U4.19 (SHDN)
GPIO19: P2.27, R2.1
GPIO20: P2.25, R3.1
GPIO21: P2.23, R4.1
GPIO22: P2.21, R6.1
GPIO23: P2.19, R7.1
GPIO24: P2.17, R8.1
GPIO25: P2.15, R9.1
GPIO26: P2.13, R10.1, U2.14 (S0)
GPIO27: P2.11, R11.1, U2.2 (S1)
GPIO28: P2.9, U4.60 (OF+/0FA)
GPIO29: P2.7, U4.63 (RAND)
I2C SCL: P2.40, R12.1, U6.4 (SCL)
I2C SDA: P2.39, R13.1, U6.5 (SDA)
IOVDD: C18.1, C20.1
unnamed: C2.1, L1.1, L4.1
unnamed: C3.1, L4.2, L5.1
unnamed: C4.1, L5.2, T2.4
unnamed: C49.2, R14.2, R15.1, T1.2
unnamed: C50.2, C52.2, T2.2
unnamed: C51.1, T1.4
unnamed: C47.1, HF_Ant1.1 (In)
unnamed: L2.1, R18.1
unnamed: L2.2, R19.2
unnamed: L3.1, R17.1
unnamed: L3.2, R20.2
unnamed: P2.3, P2.4
unnamed: C22.1, C27.1, P3.2, P5.3, R11.2
unnamed: C24.1, C28.1, P3.3, P5.4, R10.2
unnamed: C21.1, C25.1, C29.1, C30.1, P3.4, P3.5, P5.5, P5.6, R8.2, R9.2
unnamed: C23.1, C34.1, P3.9, P5.7, R3.2
unnamed: C26.1, C35.1, P3.10, P5.8, R2.2
unnamed: C36.1, P3.15, P4.1, R13.2
unnamed: C37.1, P3.16, P4.2, R12.2
unnamed: T2.1, U5.13 (+IN), U5.14 (+IN)
unnamed: T2.3, U5.15 (-IN), U5.16 (-IN)
unnamed: C1.1, L1.2, U2.7 (1A)
unnamed: C47.2, DD1.3 (K), U2.9 (2A)
unnamed: C48.1, R1.1, R14.1, T1.1, U4.12 (ENC+)
unnamed: C48.2, R1.2, R15.2, T1.3, U4.13 (ENC-)
unnamed: R5.2, U4.62 (MODE)
unnamed: R17.2, U5.8 (+OUT)
unnamed: R18.2, U5.5 (-OUT)
unnamed: C40.2, U6.7 (VDDO)
PCLK: P2.35, U4.41 (D6-/CLKOUTA)
REF CLK: Ref_Clock1.1 (In), U6.6 (CLK2)
VC6400: C41.2, C42.2, C43.2, C44.2, C45.2, C46.2, U5.1 (V+), U5.3 (V+), U5.10 (V+)
VCC: C9.1, C10.1, J1.1, U3.1 (VI)
VCM: U4.3 (VCM), U5.2 (VOCM)
VDD: C5.1, C8.1, C11.1, C12.1, C13.1, C14.1, C15.1, C16.1, C17.1, C19.1, C56.1, DD1.2 (A), R5.1, U1.3 (VI), U2.16 (VCC), U3.3 (VO), U4.1 (SENSE), U4.5 (VDD), U4.6 (VDD), U4.15 (VDD), U4.16 (VDD), U4.17 (VDD), U6.1 (VDD)
XA: C39.1, U6.2 (XA), Y1.2
XB: C38.2, U6.3 (XB), Y1.1

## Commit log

2023-07-15 Initial upload of KiCad project
    [HF103-ADC.kicad_sch, HF103-Power.kicad_sch, HF103-RF.kicad_sch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]
2023-07-16 Updated schematic PDF 2023-07-16
2023-07-19 Commit latest schematic changes
    [HF103-ADC.kicad_sch, HF103-Power.kicad_sch, HF103-RF.kicad_sch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]
